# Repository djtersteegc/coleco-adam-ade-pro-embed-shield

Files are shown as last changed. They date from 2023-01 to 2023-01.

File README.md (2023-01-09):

# Coleco Adam ADE Pro Mini OLED Edition
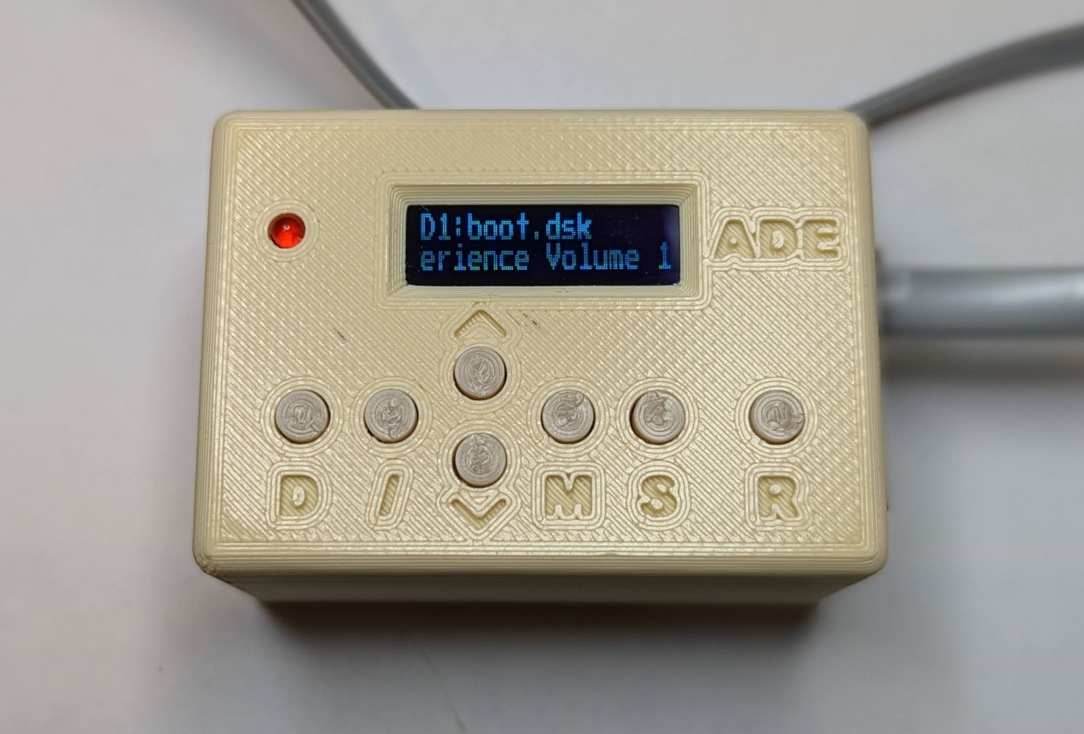
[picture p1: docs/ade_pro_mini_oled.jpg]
ade_pro_mini_oled


Yet another version of hardware compatible with the [AdamNet Drive Emulator](https://github.com/Kalidomra/AdamNet-Drive-Emulator) (ADE) software by Sean Myers. This is a smaller version of my [previous design](https://github.com/djtersteegc/coleco-adam-ade-pro-shield) now built around an (unofficial) Aruduino Mega 2560 PRO Embed board and replacing the 1602 LCD with an 0.91" I2C OLED screen and SMD components.

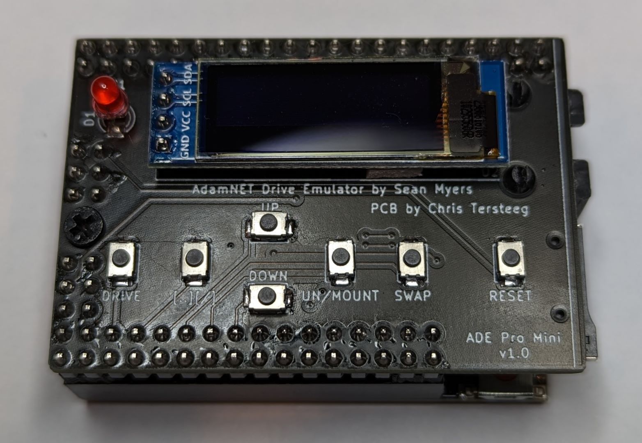
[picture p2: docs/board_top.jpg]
board_top


Here's a size comparison between the two versions.

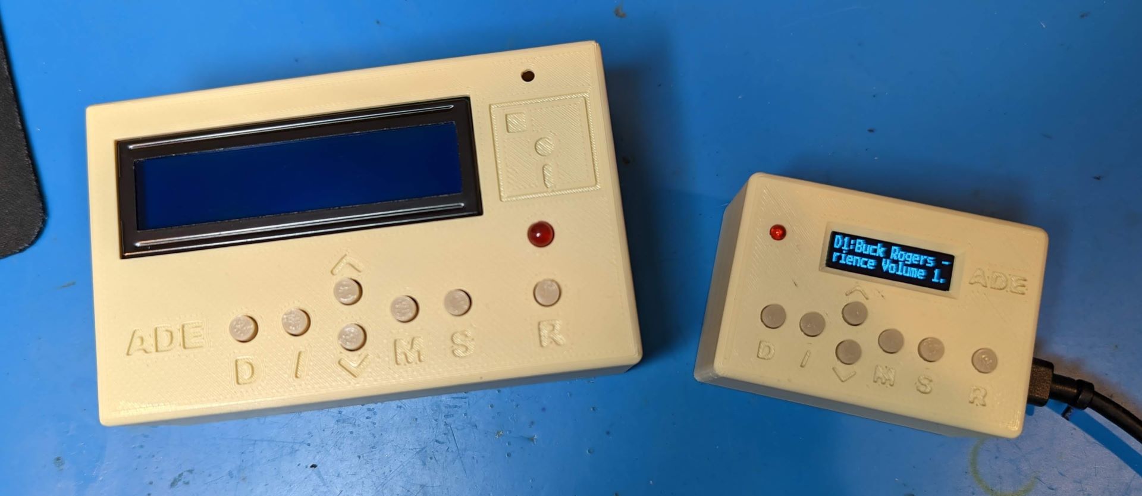
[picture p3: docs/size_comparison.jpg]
size_comparison


All components can be sourced from the usual low cost China based vendors for a total build cost of around $20.  Please see the hardware component page for more details.

[Hardware Component Choices](https://djtersteegc.github.io/coleco-adam-ade-pro-embed-shield/components.html)

An interactive BOM and parts placement diagram is also available.

[Interactive Bill of Materials (BOM)](https://djtersteegc.github.io/coleco-adam-ade-pro-embed-shield/ibom.html)

# Assembley

Even though this is mostly SMD, assembley is pretty easy since everything is 0805 sized or bigger, but you do need to follow a certain order since some components overlap each other or become difficult to reach. Start by doing all the SMD components (resistors, caps, IC, transistor, and SD card socket) on the underside of the board. I used solder paste and hot air, but you could also hand solder these. Pay attention to the orientaion of the two polarized caps if you elect to install them.

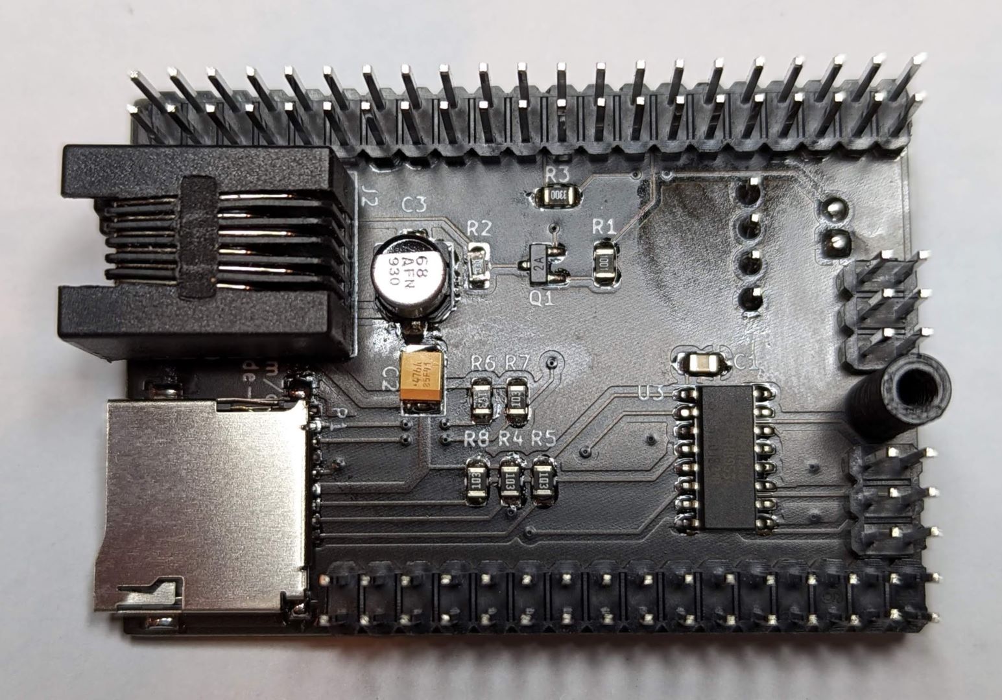
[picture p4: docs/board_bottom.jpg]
board_bottom


Then flip the boad over and install the switches.  For this I used solder paste and a hand iron.

Next install the RJ12 jack.

I soldered the headers on next, but you could also the do the OLED and LED if you don't want to seperate the boards again after soldering the headers on.  I tend to do the OLED last just to minimize the chance of breaking it.  For the LED I placed the top half of the board in the case and used a 1mm spacer under the case top of get a nice reveal and then soldered it in. For the OLED I installed in on 3mm thick double sided foam tape and then soldered the headers on once I confirmed it was straight.  

For the headers I like to screw in the two 14.6mm spacers and assemble the two halves to make sure everything stays aligned.  Use M2.5x6mm (or longer) screws for the spacers.  The one with the cut on the top goes in the hole by the SD card with the cut out area facing the SD card socket.

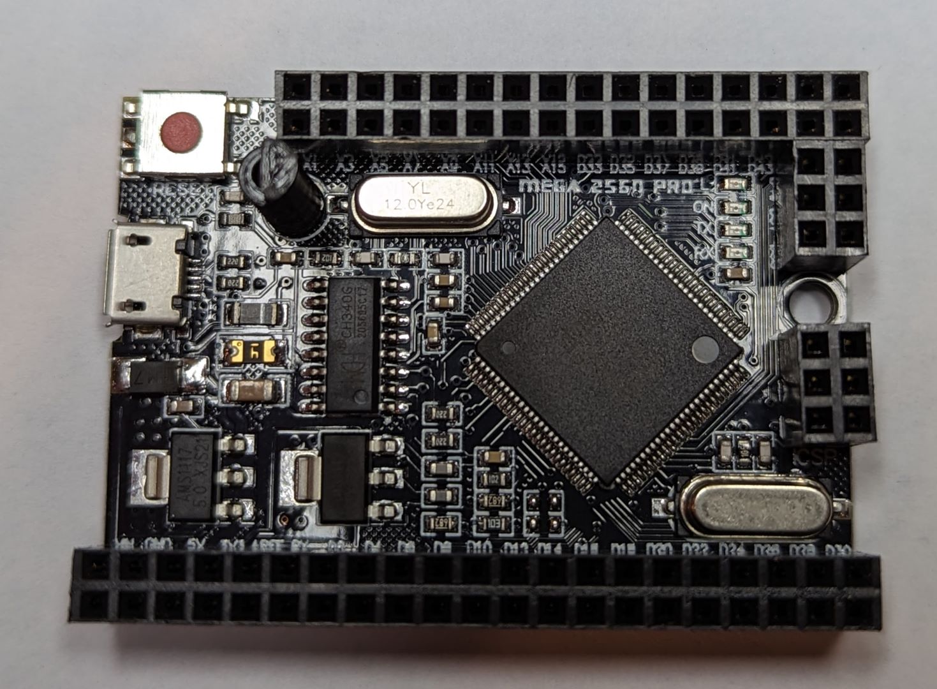
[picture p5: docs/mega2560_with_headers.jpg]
mega2560_with_headers


After everything is soldered I then inserted four of the 3.6mm header block spacers in all four corners to ensure everything stayed leveled and the male header pin aren't pushed to far into the female headers.

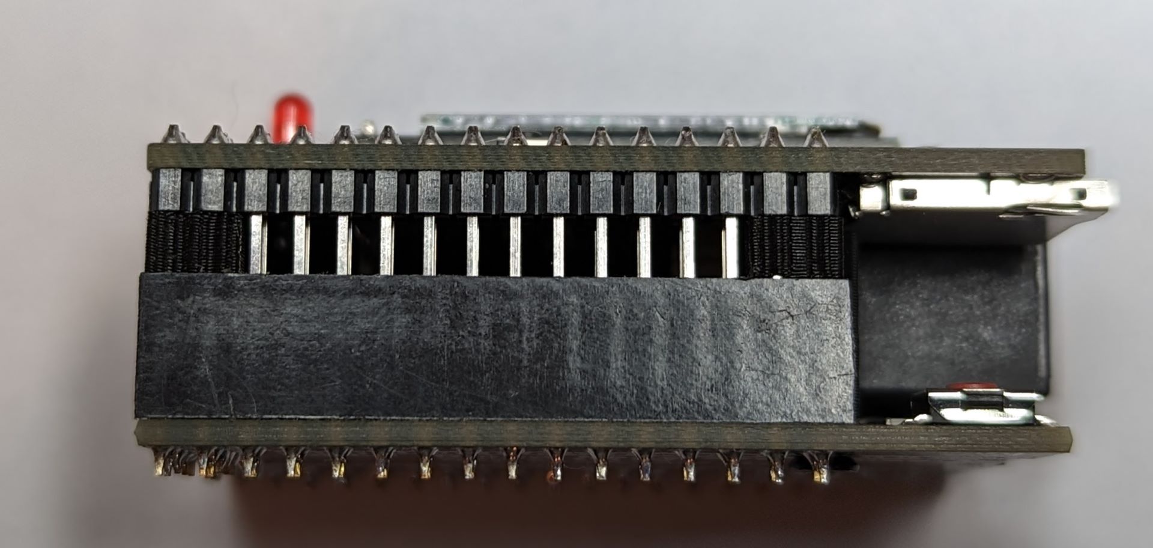
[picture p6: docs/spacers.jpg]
spacers


# Programming

This version does require updates to Sean's original ADE code base to support the OLED screen and remaps a number of pins to support this PCB layout.   I have a fork of his repo [here](https://github.com/djtersteegc/AdamNet-Drive-Emulator), and there is a precompiled ADE-Pro-Mini-OLED_v0.92.hex binary if you just want to upload via something like AVRDude.

If you decided to build it yourself, make sure 

`#define PRO_MINI_OLED_BOARD`

is uncommented in AdamNet_Drive_Emulator.ino.  I used the u8x8 library for the OLED screen, but even with hardware I2C, the refresh rate is still much slower than the old 1602 LCD.  You don't notice it when viewing the screen, but it was enough to throw off the AdamNET timing when dumping debug info to the screen so that functionality has been disabled in this version (debug messages still are sent over the serial port).

# Debugging and Power

Power comes directly from the AdamNET connector and there are no onboard jumpers or diodes to prevent backfeeding if you also plug in the Arduino while  connected to the Adam.  That's why there is no cutout in the cover for the USB connector.  If you do need to connect the USB port for serial debugging, you can create an AdamNET RJ12 cable with the 5V line (pin 6 on the ADE side) disconnected.

# Case

STL's and the [DesignSpark Mechanical](https://www.rs-online.com/designspark/mechanical-software) source file for a 3D printable enclosure and the various standoff and spacers are in the **case** directory. Make sure to print seven copies of the button file and four copies of the 3.6mm spacer.

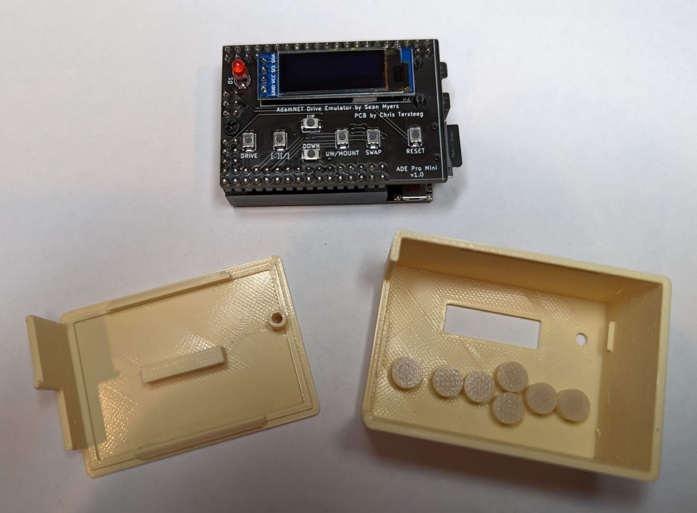
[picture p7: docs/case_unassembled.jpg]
case_unassembled


There are two versions of the lid file, one that covers the UBS port (the one most people should use), and one that exposes it for development purposes.  Read the warining about powering via USB above!  The lid is snap fit, but the is also a provision to screw it into the bottom of one of the spacers using a m2.5x15mm (or longer) scew.

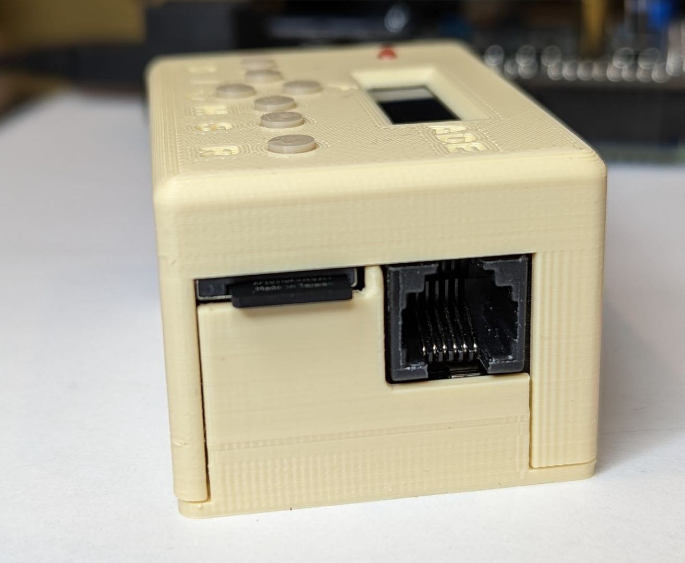
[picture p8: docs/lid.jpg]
lid


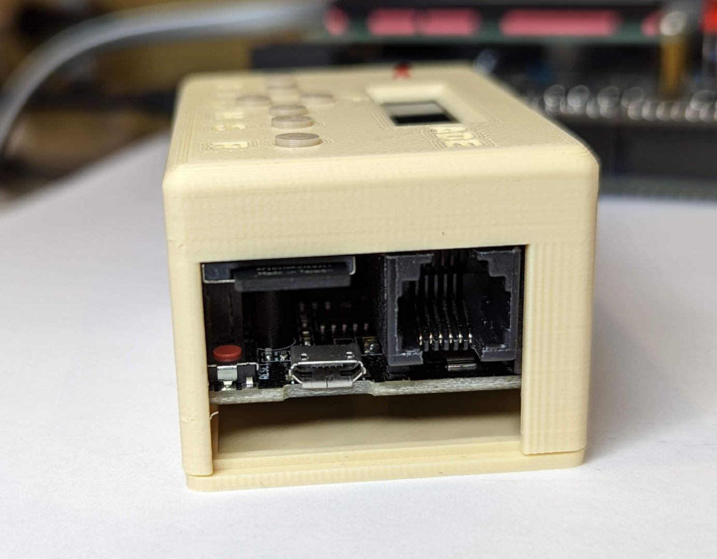
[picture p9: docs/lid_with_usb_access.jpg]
lid_with_usb_access


# Getting a Board

If I have extra PCB's, they will be listed on Tindie (soon...).

Otherwise you can download the Gerbers and use your favorite fab (JLCPCB, PCBWay, etc.) to make your own batch.  It's a standard two layer, 1oz copper board with dimensions of 56mm x 38mm.

# Hardware Revisions

### Version 1.0

Tested and working.

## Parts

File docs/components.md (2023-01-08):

# Hardware Component Choices

[Interactive Bill of Materials (BOM)](ibom.html)

### Arduino

The Mega 2560 PRO Embed board is an unoffical "clone" of the Mega2560 that appears to orginally have been done by DFRobot, but is now available from all the usual Chinese vendors.   I got several [here](https://www.aliexpress.us/item/2251832723188280.html) for less than $10, and they have all worked fine.

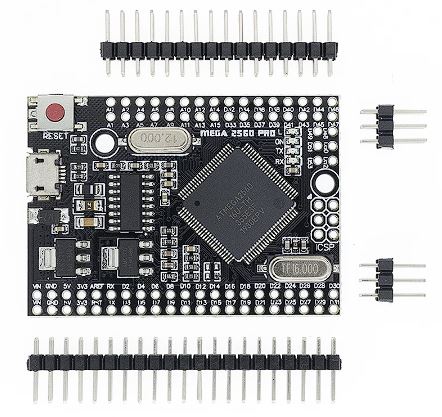
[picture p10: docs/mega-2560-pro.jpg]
spacers
 

### OLED

Any old 0.91" I2C (or IIC) OLED with the SSD1306 controller will do.  Many have the four pin header soldered on crooked so be prepared to fix that. :(

### Micro SD Card Connector

Push-push style with the two plastic locating pins on the front. My roll of 50 came from [here](https://www.aliexpress.us/item/2251832614001800.html).

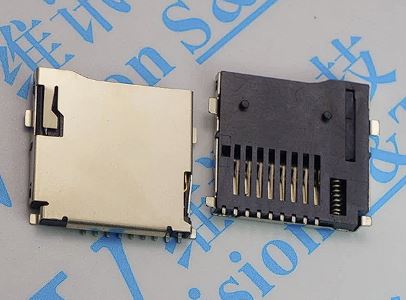
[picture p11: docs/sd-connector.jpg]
sd-connector


### RJ12 Connector

The "longer" type RJ12 connector from [Aliexpress](https://www.aliexpress.com/item/32865986654.html) work fine if you don't want to spring for the official [Amphenol](https://www.digikey.com/en/products/detail/amphenol-icc-fci/54601-906WPLF/4242891) version.  Remember, ADAMnet takes a RJ12 reverse cable, I get mine at [Monoprice](https://www.monoprice.com/product?p_id=939)

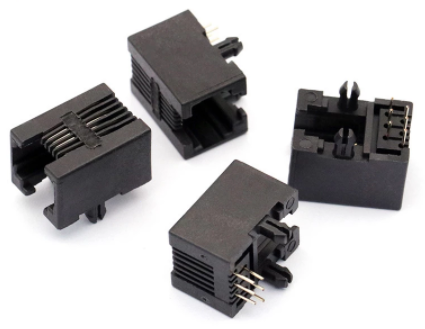
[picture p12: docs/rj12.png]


### Switches

3x4x2mm SMD tact switches. Mine can from [here](https://www.aliexpress.us/item/2251832668857119.html).

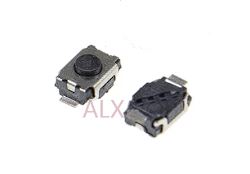
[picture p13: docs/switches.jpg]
switches


### Bulk Capacitors

C3 is a bulk storage capacitor for the 5V rail.  It is optional since the Arduino already has caps on-board, but if you have a marginal ADAMnet 5V line or experience other power issues, they could help stabilize the overall board.  Any value between 10uf to 68uf is fine.

C2 is a tantalum (yes, evil, I know) to handle SD card inrush current if you hot swap the card.  Again, optional if don't plan on switching cards without powering down first.

### Resistors

R3 controls the activity LED brightness. 330R or higher will be fine. A good calculator is at:

[http://ledcalc.com/](http://ledcalc.com/)

### Arduino Pin Headers

To accomodate the RJ12 connector in the sandwhich board confirguration, I had to use higher than normal pin headers.  Since this is meant to the be a "cheap" build, I used the common [8.5mm high double row 2.5mm pitch female headers](https://www.aliexpress.us/item/2251832703602124.html), with [15mm high double row 2.5mm pitch male headers](https://www.aliexpress.us/item/2251832707632877.html) that are also readily availble on AliExpress with 3D printed 3.6mm spacers . I bought the 40 pin versions and just cut them down to the various sizes I needed since it was the cheapest optinon. :)

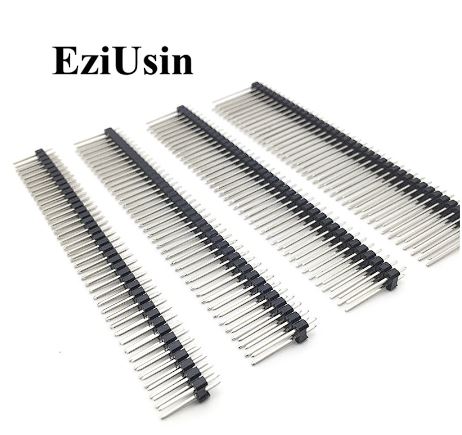
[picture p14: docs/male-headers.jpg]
male-headers


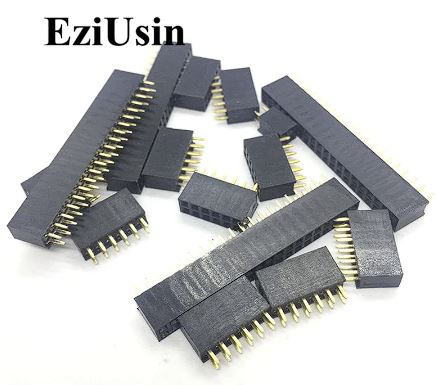
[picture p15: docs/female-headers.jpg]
female-headers


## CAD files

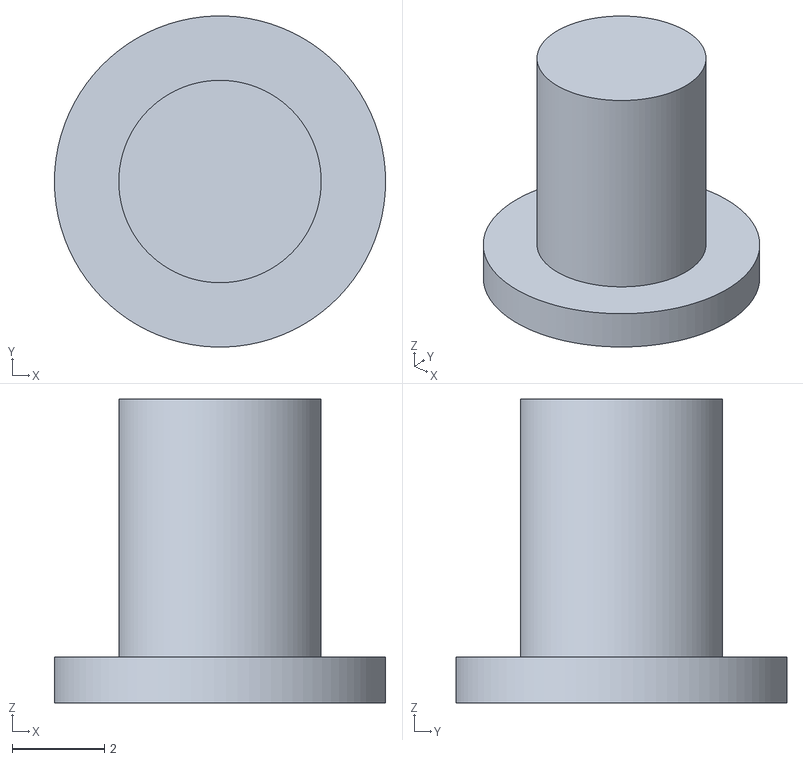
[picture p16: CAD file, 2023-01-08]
case/ade-mini-button.stl
7.20 x 7.20 x 6.60

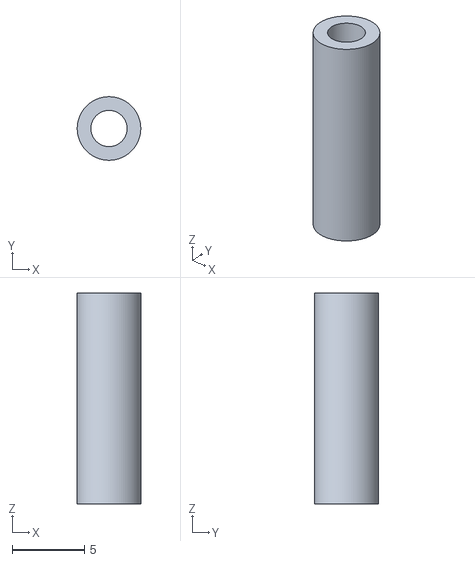
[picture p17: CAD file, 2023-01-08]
case/ade-mini-14.6mm-m2.5-spacer.stl
4.40 x 4.40 x 14.6

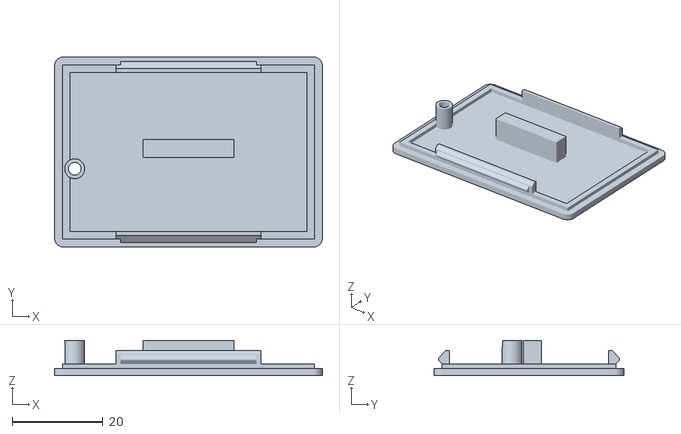
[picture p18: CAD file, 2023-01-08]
case/ade-mini-lid-usb-access.stl
59.2 x 42.0 x 7.80

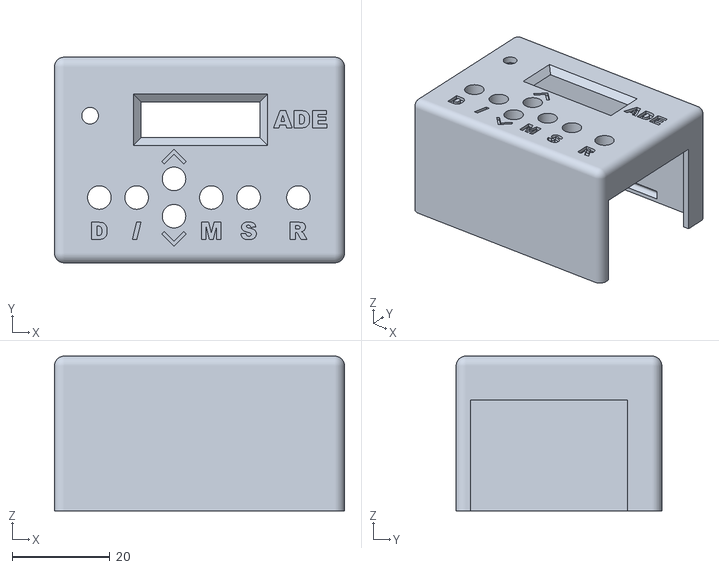
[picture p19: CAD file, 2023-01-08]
case/ade-mini-body.stl
59.2 x 42.0 x 31.6

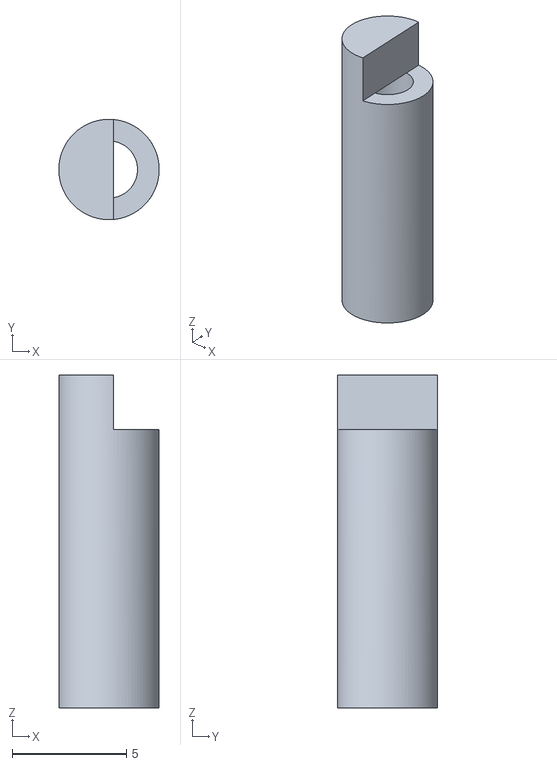
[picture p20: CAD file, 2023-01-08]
case/ade-mini-14.6mm-m2.5-cut-spacer.stl
4.40 x 4.40 x 14.6

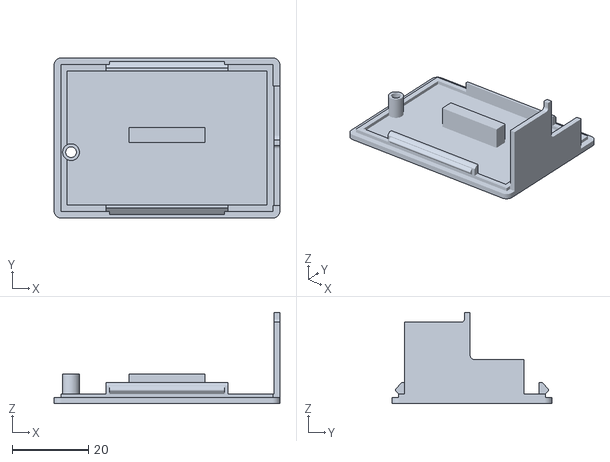
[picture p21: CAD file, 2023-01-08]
case/ade-mini-lid.stl
59.2 x 42.0 x 23.9

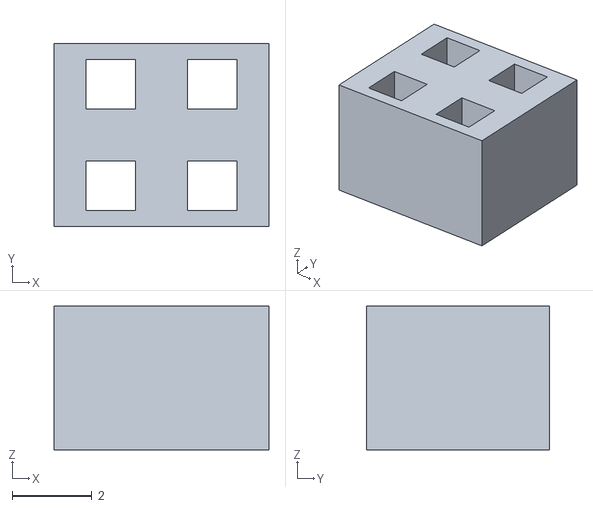
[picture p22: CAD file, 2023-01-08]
case/ade-mini-3.6mm-spacer.stl
5.38 x 4.58 x 3.60

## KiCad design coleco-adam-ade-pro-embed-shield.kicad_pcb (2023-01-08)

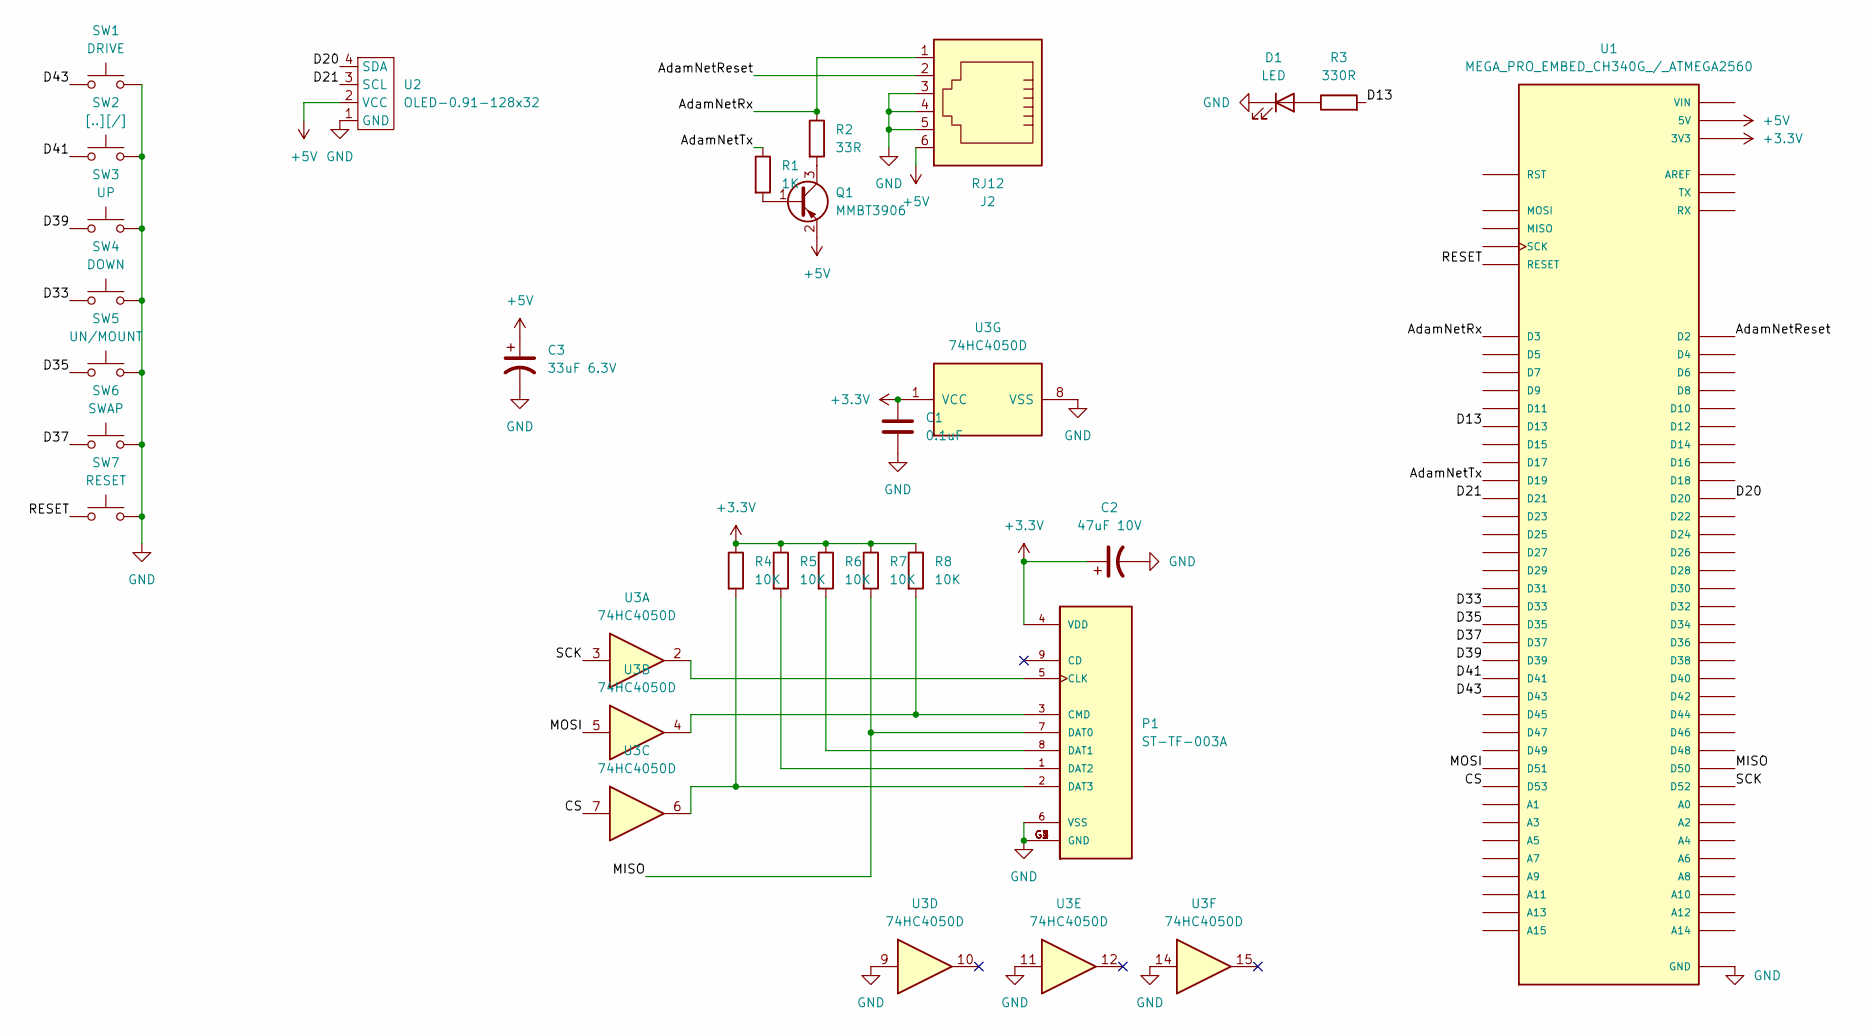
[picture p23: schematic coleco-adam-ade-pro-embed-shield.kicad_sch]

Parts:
C1: 0.1uF; C_0805_2012Metric_Pad1.18x1.45mm_HandSolder
C2: 47uF 10V; CP_EIA-3528-21_Kemet-B_Pad1.50x2.35mm_HandSolder
C3: 33uF 6.3V; CP_Elec_5x5.8
D1: LED; LED_D3.0mm
J2: RJ12; RJ12_Amphenol_54601
P1: ST-TF-003A; SUNTECH_ST-TF-003A
Q1: MMBT3906; SOT-23
R1: 1K; R_0805_2012Metric_Pad1.20x1.40mm_HandSolder
R2: 33R; R_0805_2012Metric_Pad1.20x1.40mm_HandSolder
R3: 330R; R_0805_2012Metric_Pad1.20x1.40mm_HandSolder
R4, R5, R6, R7, R8: 10K; R_0805_2012Metric_Pad1.20x1.40mm_HandSolder
SW1: DRIVE; SW_Push_SPST_NO_Alps_SKRK
SW2: [..][/]; SW_Push_SPST_NO_Alps_SKRK
SW3: UP; SW_Push_SPST_NO_Alps_SKRK
SW4: DOWN; SW_Push_SPST_NO_Alps_SKRK
SW5: UN/MOUNT; SW_Push_SPST_NO_Alps_SKRK
SW6: SWAP; SW_Push_SPST_NO_Alps_SKRK
SW7: RESET; SW_Push_SPST_NO_Alps_SKRK
U1: MEGA_PRO_EMBED_CH340G_/_ATMEGA2560; MODULE_MEGA_PRO_EMBED_CH340G___ATMEGA2560; PARTREV 12/May/2017
U2: OLED-0.91-128x32
U3: 74HC4050D; SOIC-16_3.9x9.9mm_P1.27mm

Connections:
+3.3V: C1.2, C2.1, P1.4 (VDD), R4.1, R5.1, R6.1, R7.1, R8.1, U1.3V3_1 (3V3), U1.3V3_2 (3V3), U3.1 (VCC)
+5V: C3.1, J2.6, Q1.2 (E), U1.5V_1 (5V), U1.5V_2 (5V), U1.5V_3 (5V), U2.2 (VCC)
/AdamNetReset: J2.2, U1.D2
/AdamNetRx: J2.1, R2.1, U1.D3
/AdamNetTx: R1.1, U1.D19
/CS: U1.D53, U3.7
/D13: R3.2, U1.D13
/D20: U1.D20, U2.4 (SDA)
/D21: U1.D21, U2.3 (SCL)
/D33: SW4.1, U1.D33
/D35: SW5.1, U1.D35
/D37: SW6.1, U1.D37
/D39: SW3.1, U1.D39
/D41: SW2.1, U1.D41
/D43: SW1.1, U1.D43
/MISO: P1.7 (DAT0), R7.2, U1.D50
/MOSI: U1.D51, U3.5
/RESET: SW7.1, U1.RESET
/SCK: U1.D52, U3.3
GND: C1.1, C2.2, C3.2, D1.1 (K), J2.3, J2.4, J2.5, P1.6 (VSS), P1.G1 (GND), P1.G2 (GND), P1.G3 (GND), P1.G4 (GND), SW1.2, SW2.2, SW3.2, SW4.2, SW5.2, SW6.2, SW7.2, U1.GND_1 (GND), U1.GND_2 (GND), U1.GND_3 (GND), U2.1 (GND), U3.8 (VSS), U3.9, U3.11, U3.14
unnamed: D1.2 (A), R3.1
unnamed: P1.1 (DAT2), R5.2
unnamed: P1.2 (DAT3), R4.2, U3.6
unnamed: P1.3 (CMD), R8.2, U3.4
unnamed: P1.5 (CLK), U3.2
unnamed: P1.8 (DAT1), R6.2
unnamed: Q1.1 (B), R1.2
unnamed: Q1.3 (C), R2.2
unnamed: U1.VIN_1 (VIN), U1.VIN_2 (VIN)

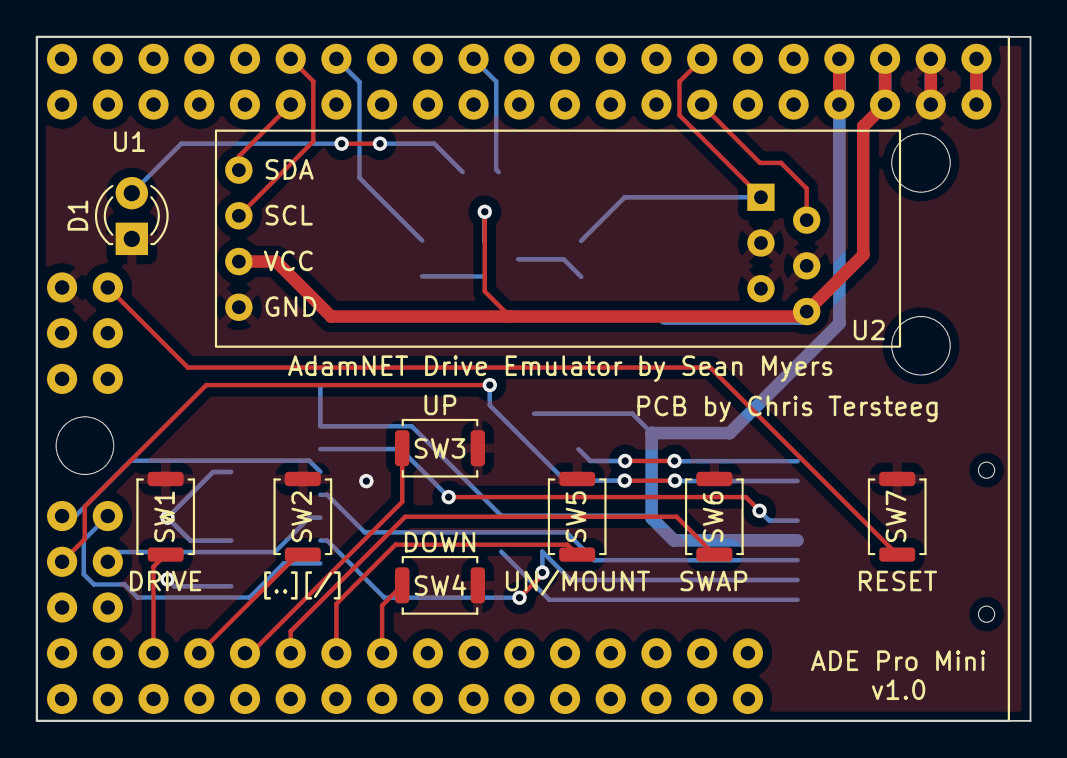
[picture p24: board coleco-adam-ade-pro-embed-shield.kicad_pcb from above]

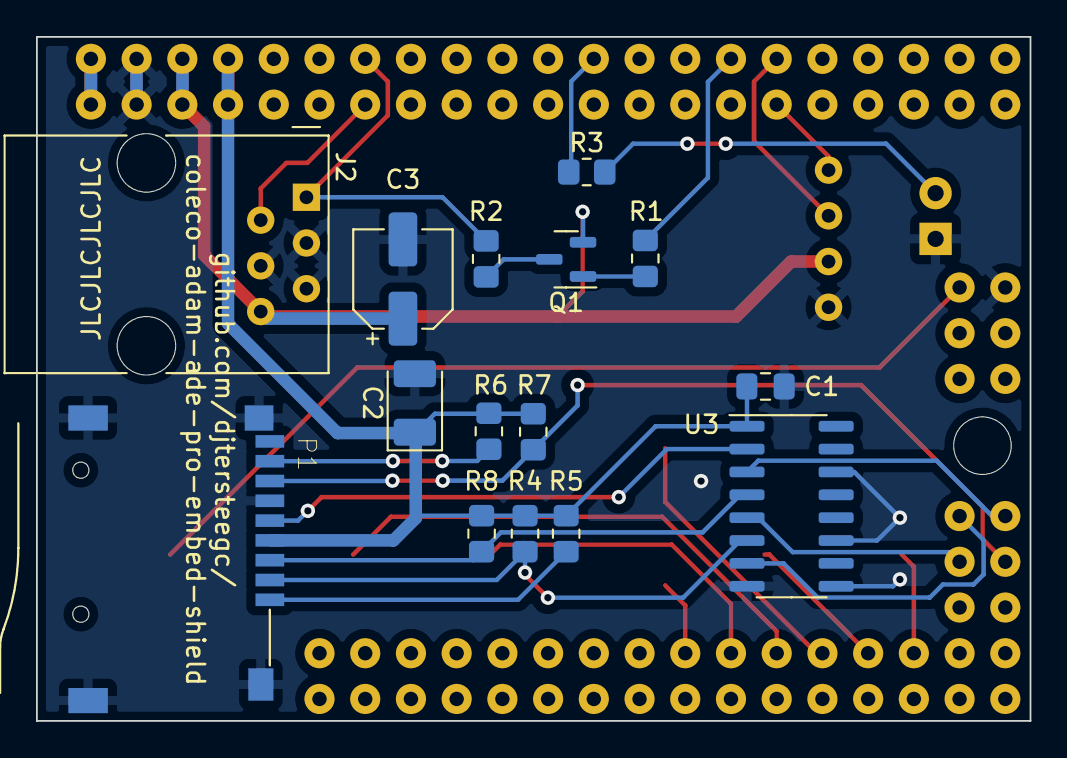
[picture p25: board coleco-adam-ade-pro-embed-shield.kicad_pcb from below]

Board: 2 copper layers, 55.2 x 38.0 mm, 25 parts (15 on the bottom side), 29 nets.
